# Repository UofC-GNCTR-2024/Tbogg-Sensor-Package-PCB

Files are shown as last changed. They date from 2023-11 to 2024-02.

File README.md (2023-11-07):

# Tbogg-Sensor-Package-PCB
The sensor package (strain, temperature, vibration) for the 2024 UofC GNCTR tbogg. Designed as an R&amp;D intrastructure monitoring solution.

## Main Components

1. **2x** Strain Gauge Blocks
	* Ulimately reads one of these two strain gauges:
		1. [100x BF350-3AA](https://www.aliexpress.com/item/595240806.html)
		2. [10x BX120-2AA](https://www.aliexpress.com/item/1005003672107724.html)
	* Based on [this schematic](https://www.elecrow.com/strain-gauge-module-p-735.html)
	* Sensing via HX711 chip
2. **1x** On-PCB Temperature Sensor (STDS75DS2F)
	* I2C
3. **2x** In-Concrete Temperature Sensors
	* Thermistor-based
4. **1x** Vibration Sensor
	* Model: MPU-6050 Breakout
	* I2C Comms
5. I2C Optical Flow Sensor
6. Battery: 4x 18650
	* TODO: choose quantity, model, holder, and connection
	* In series
7. Battery Management System: probably the 3V3 buck-boost from the balloon project
	* TODO: more info
8. Wireless Comms: LoRa Wio E5
	* TODO: pull from balloon project
	* TODO: confirm that this model is good
9. Microcontroller Unit (MCU)
	* ESP32 Breakout

## Reference Links
* TODO: fill

## Revision Notes
* PCB orders will each recieve a new revision number. 
	* PCB orders will be in the format of "Rev1", "Rev2", etc.
	* GitHub Releases (and Tags) will be tagged in the format of `rev1`, `rev2`, etc.
* BOM changes on PCB orders should be documented as minor revisions.
	* Example: `rev1.1`, `rev1.2`, etc.

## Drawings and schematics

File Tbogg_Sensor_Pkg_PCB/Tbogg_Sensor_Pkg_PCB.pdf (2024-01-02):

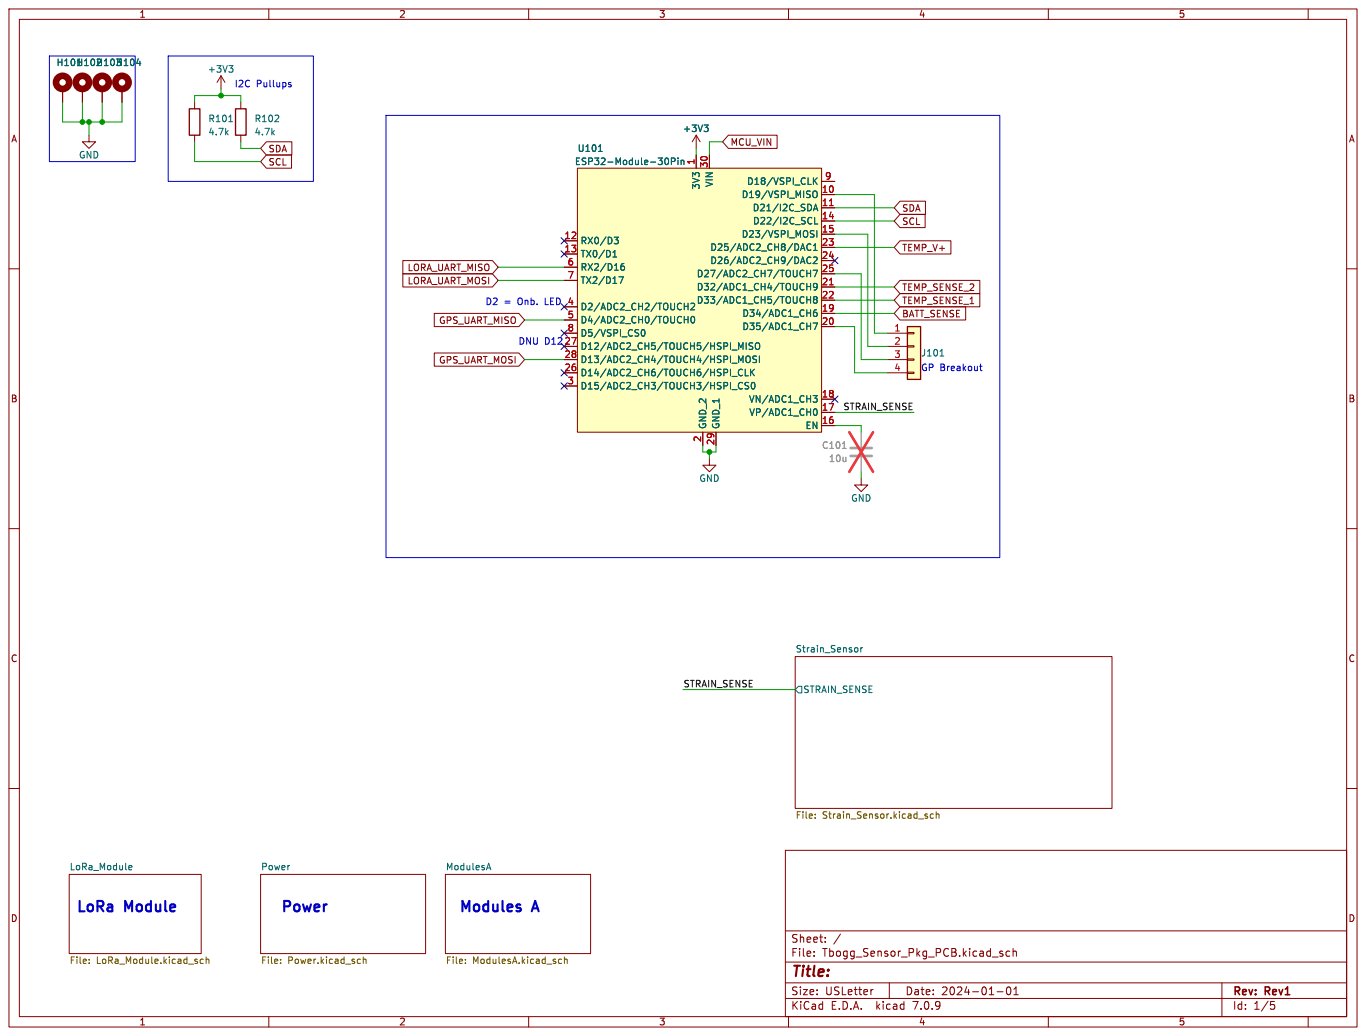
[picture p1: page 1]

File: ModulesA.kicad_sch Power File: Power.kicad_sch

Id: 1/5 Title: File: Tbogg_Sensor_Pkg_PCB.kicad_sch Sheet: / ModulesA

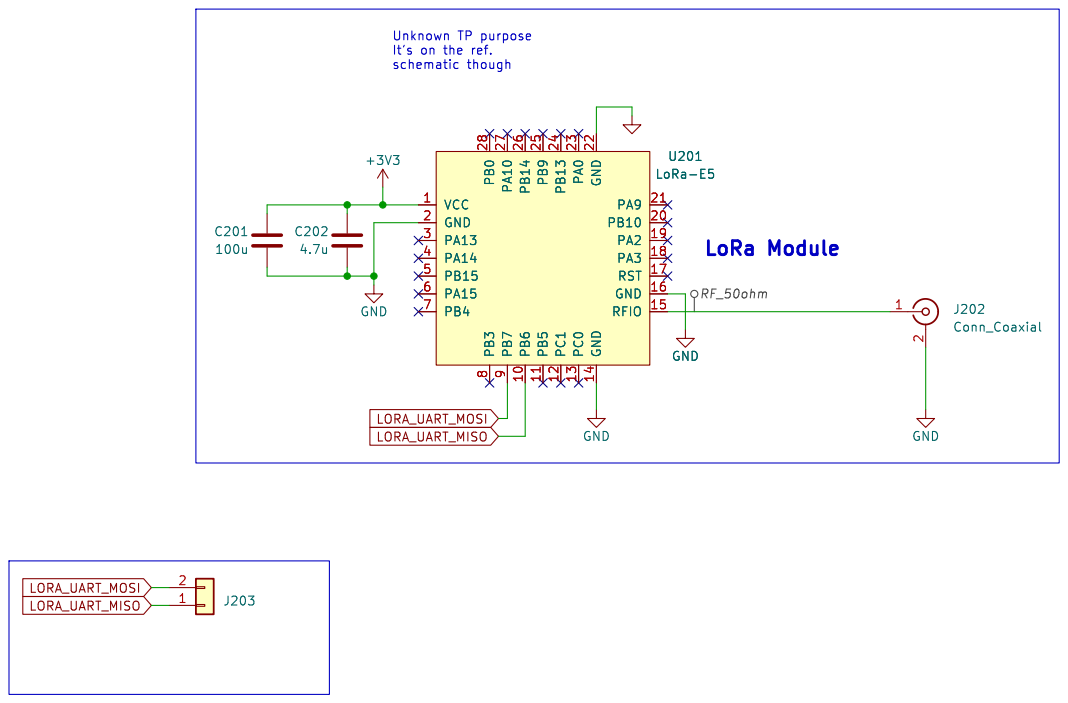
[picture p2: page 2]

Id: 2/5 Title: File: LoRa_Module.kicad_sch Sheet: /LoRa_Module/ GND

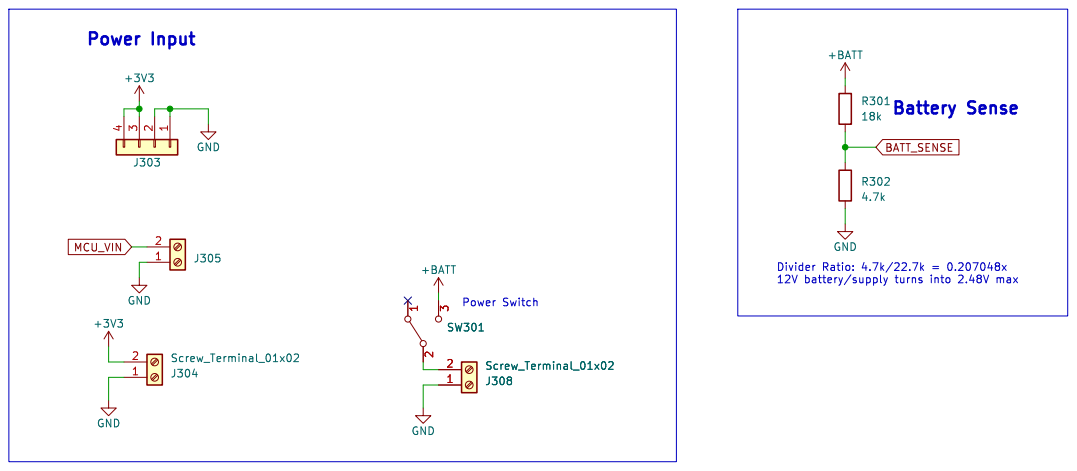
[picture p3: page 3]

J308 Screw_Terminal_01x02 +BATT GND GND GND

Id: 3/5 Title: File: Power.kicad_sch Sheet: /Power/

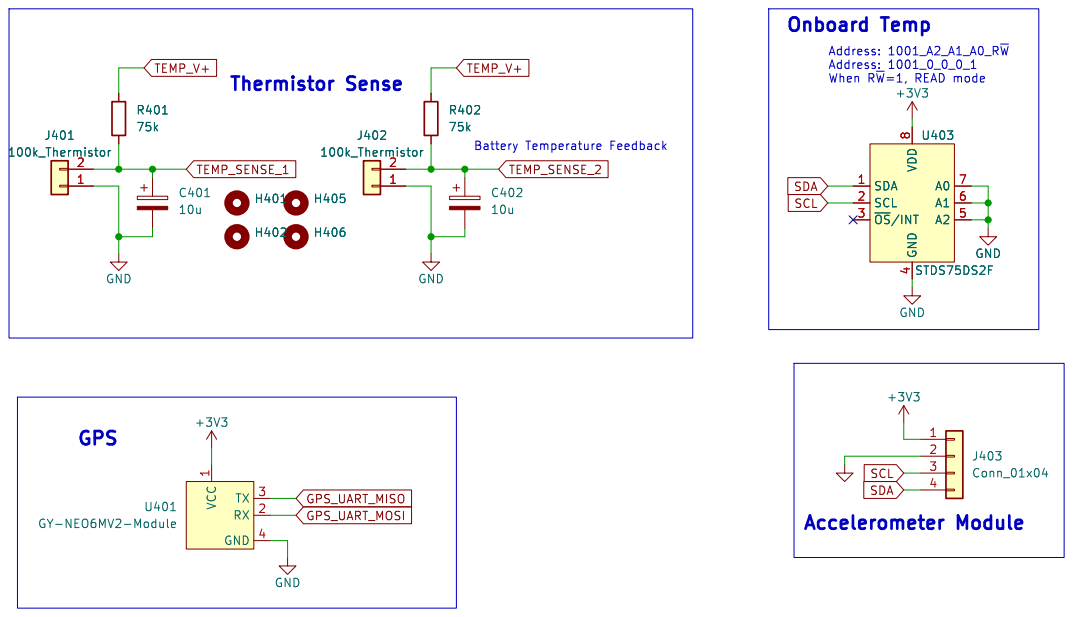
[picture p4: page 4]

1 RX 2 TX 3 GND 4 U401 GY-NEO6MV2-Module +3V3 GND
GPS

Id: 4/5 Title: File: ModulesA.kicad_sch Sheet: /ModulesA/

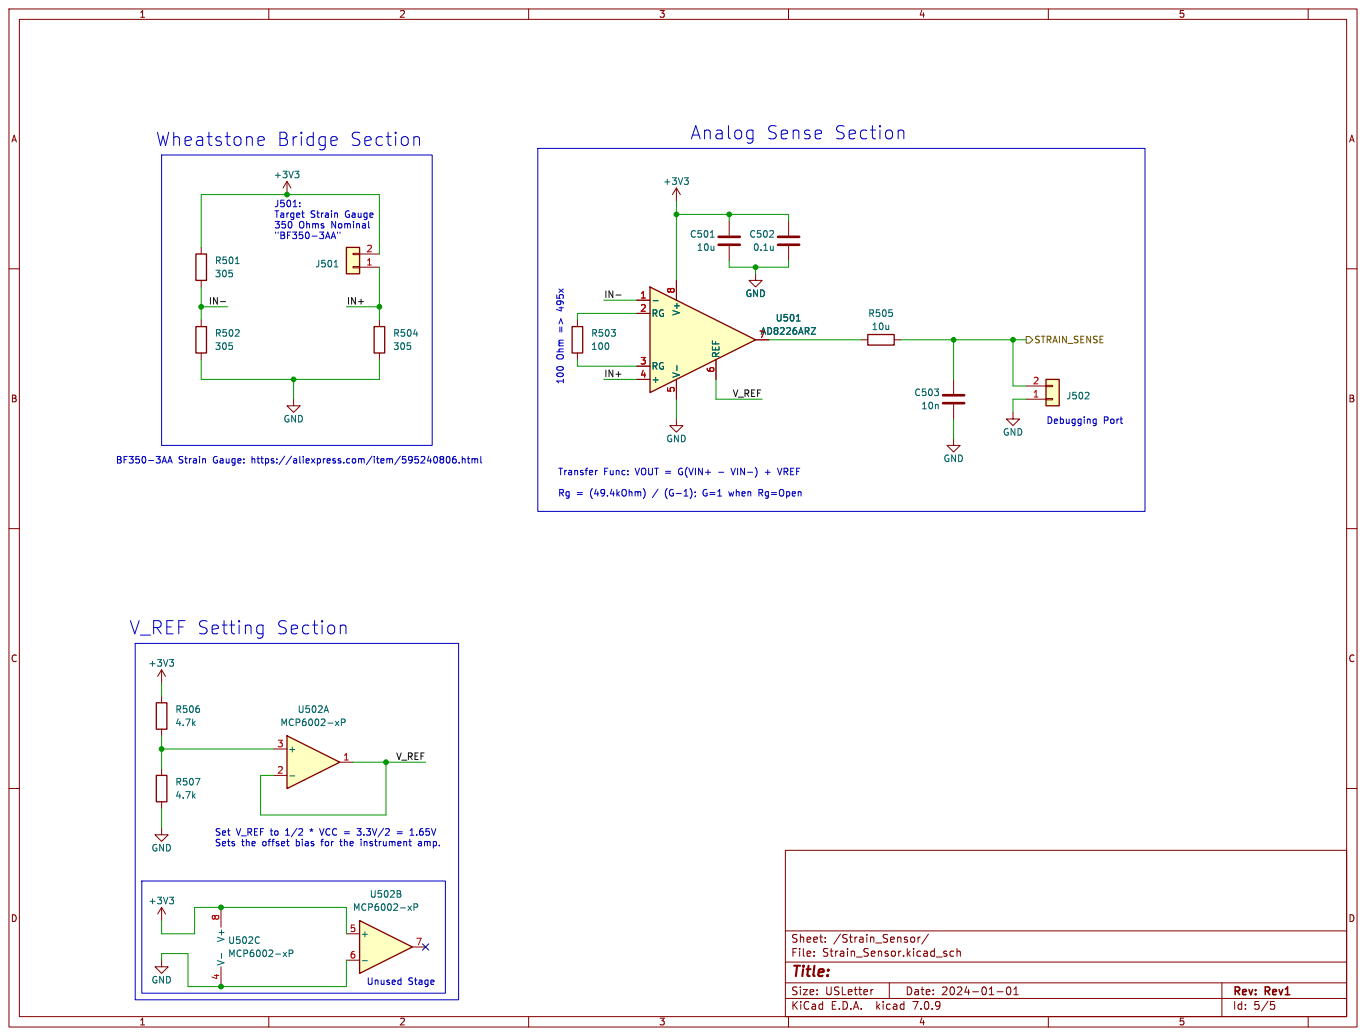
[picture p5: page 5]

350 Ohms Nominal "BF350-3AA" Wheatstone Bridge Section

Id: 5/5 Title: File: Strain_Sensor.kicad_sch Sheet: /Strain_Sensor/

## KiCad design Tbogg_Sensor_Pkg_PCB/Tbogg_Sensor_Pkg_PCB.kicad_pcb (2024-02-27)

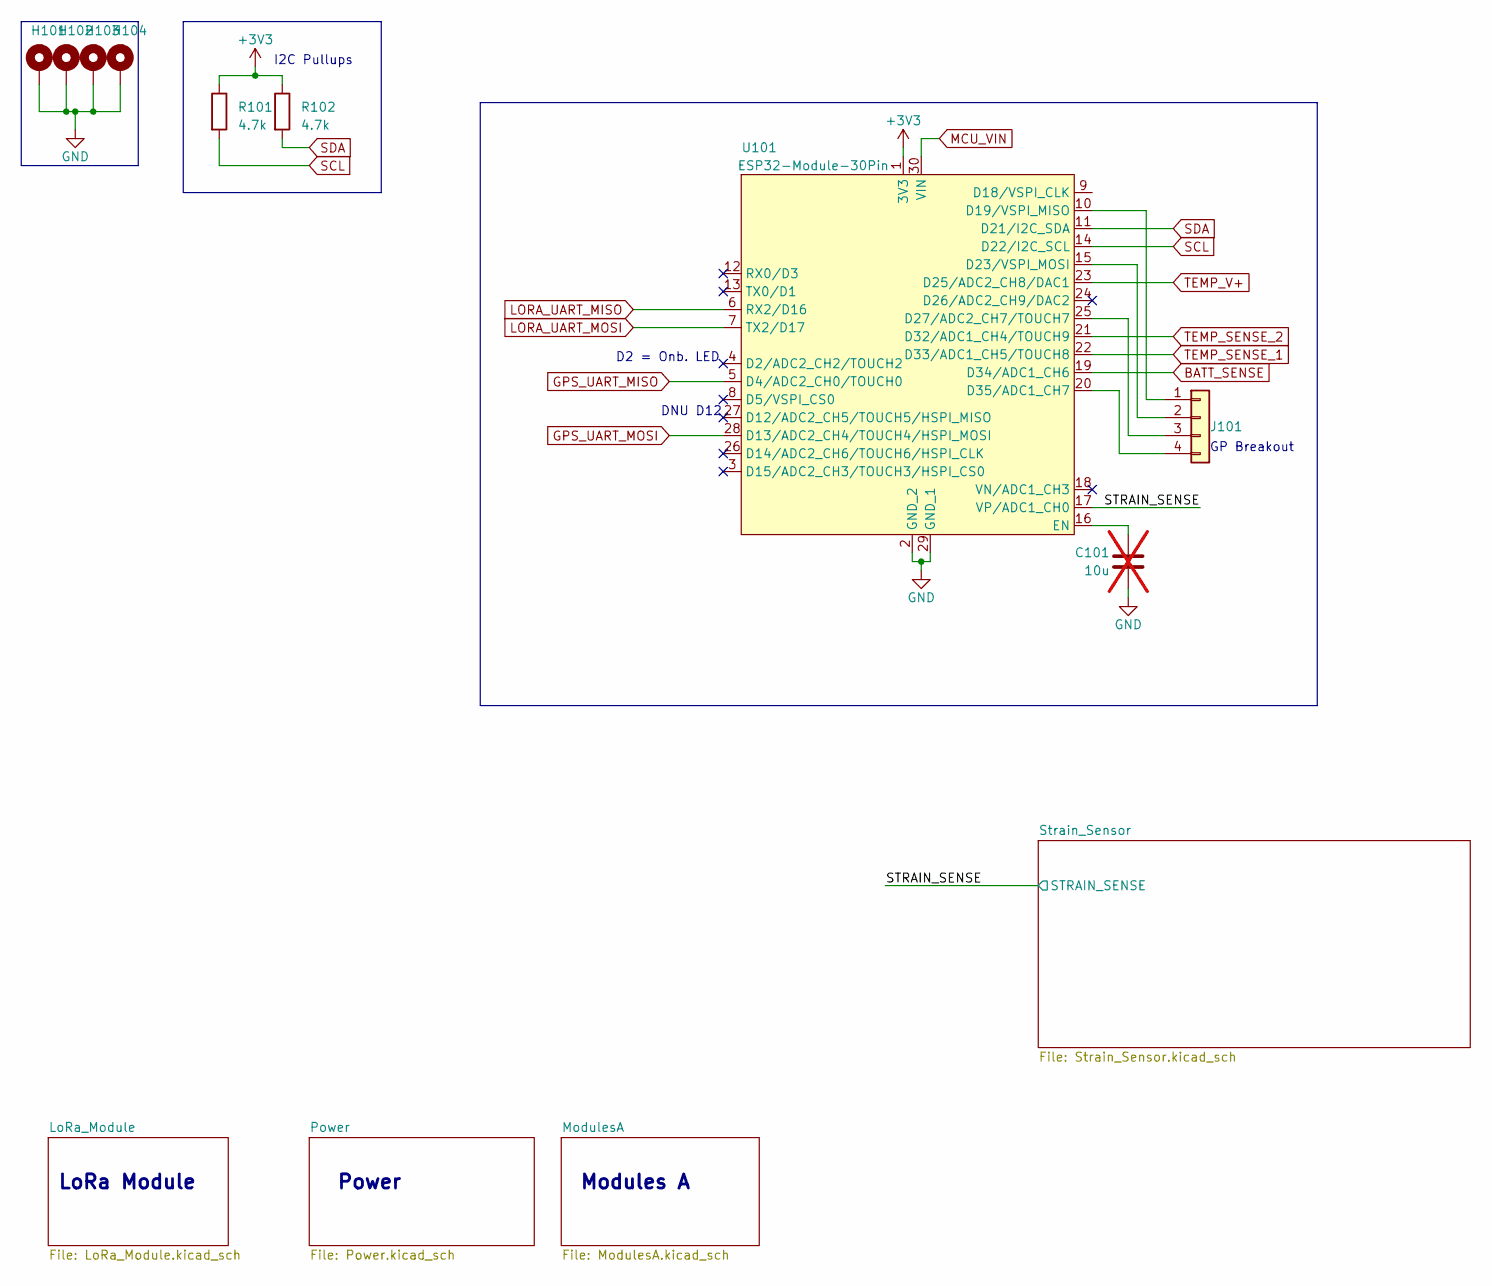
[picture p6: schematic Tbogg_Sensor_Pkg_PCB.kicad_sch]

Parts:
C101: 10u; C_1206_3216Metric_Pad1.33x1.80mm_HandSolder; not fitted
H101, H102, H103, H104: MountingHole_Pad; MountingHole_3.2mm_M3_DIN965_Pad
J101: Conn_01x04; PinHeader_1x04_P2.54mm_Vertical
R101, R102: 4.7k; R_1206_3216Metric_Pad1.30x1.75mm_HandSolder
U101: ESP32-Module-30Pin

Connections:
BATT_SENSE: U101.19 (D34/ADC1_CH6); also elsewhere on the board
GND: C101.2, H101.1, H102.1, H103.1, H104.1, U101.2 (GND_2), U101.29 (GND_1); also elsewhere on the board
GPS_UART_MISO: U101.5 (D4/ADC2_CH0/TOUCH0); also elsewhere on the board
GPS_UART_MOSI: U101.28 (D13/ADC2_CH4/TOUCH4/HSPI_MOSI); also elsewhere on the board
LORA_UART_MISO: U101.6 (RX2/D16); also elsewhere on the board
LORA_UART_MOSI: U101.7 (TX2/D17); also elsewhere on the board
MCU_VIN: U101.30 (VIN); also elsewhere on the board
unnamed: J101.1, U101.10 (D19/VSPI_MISO)
unnamed: J101.2, U101.15 (D23/VSPI_MOSI)
unnamed: J101.3, U101.25 (D27/ADC2_CH7/TOUCH7)
unnamed: J101.4, U101.20 (D35/ADC1_CH7)
unnamed: C101.1, U101.16 (EN)
SCL: R101.2, U101.14 (D22/I2C_SCL); also elsewhere on the board
SDA: R102.2, U101.11 (D21/I2C_SDA); also elsewhere on the board
TEMP_SENSE_1: U101.22 (D33/ADC1_CH5/TOUCH8); also elsewhere on the board
TEMP_SENSE_2: U101.21 (D32/ADC1_CH4/TOUCH9); also elsewhere on the board
TEMP_V+: U101.23 (D25/ADC2_CH8/DAC1); also elsewhere on the board

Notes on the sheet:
LoRa Module
GP Breakout
D2 = Onb. LED
Modules A
DNU D12
Power
I2C Pullups

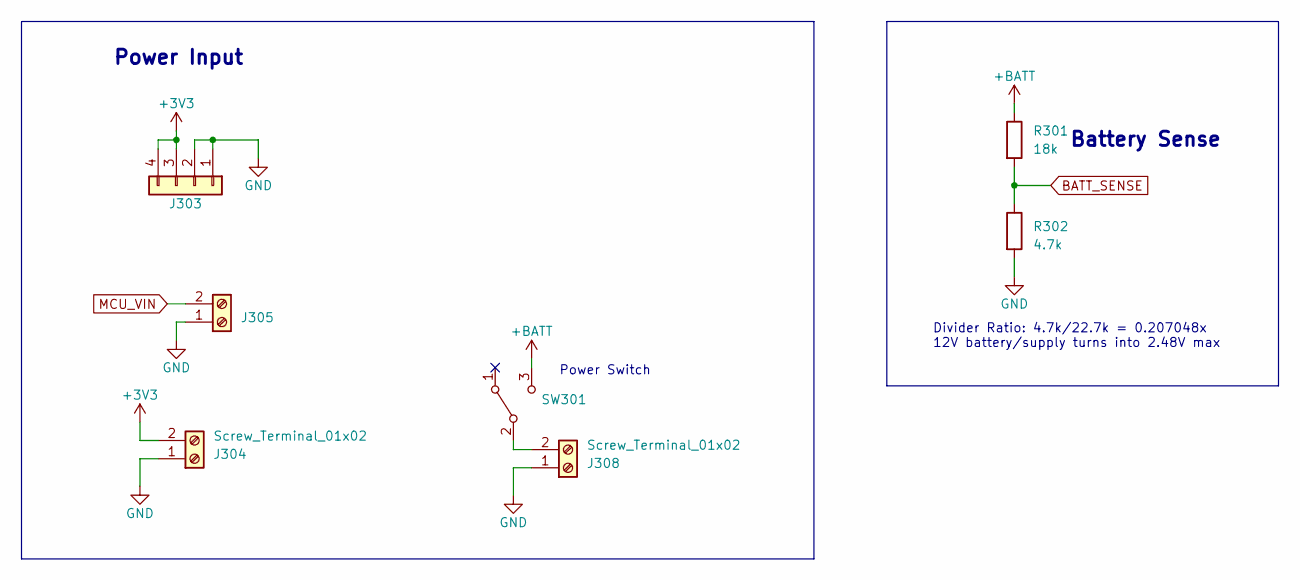
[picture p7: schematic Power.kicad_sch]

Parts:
J303: Conn_01x04; PinHeader_1x04_P2.54mm_Vertical
J304, J305, J308: Screw_Terminal_01x02; TerminalBlock_bornier-2_P5.08mm
R301: 18k; R_1206_3216Metric_Pad1.30x1.75mm_HandSolder
R302: 4.7k; R_1206_3216Metric_Pad1.30x1.75mm_HandSolder
SW301: SW_SPDT; SW_Slide_1P2T_CK_OS102011MS2Q

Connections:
+BATT: R301.1, SW301.3 (C)
BATT_SENSE: R301.2, R302.1; also elsewhere on the board
GND: J303.1, J303.2, J304.1, J305.1, J308.1, R302.2; also elsewhere on the board
MCU_VIN: J305.2; also elsewhere on the board
unnamed: J308.2, SW301.2 (B)

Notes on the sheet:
Divider Ratio: 4.7k/22.7k = 0.207048x 12V battery/supply turns into 2.48V max
Power Switch
Battery Sense
Power Input

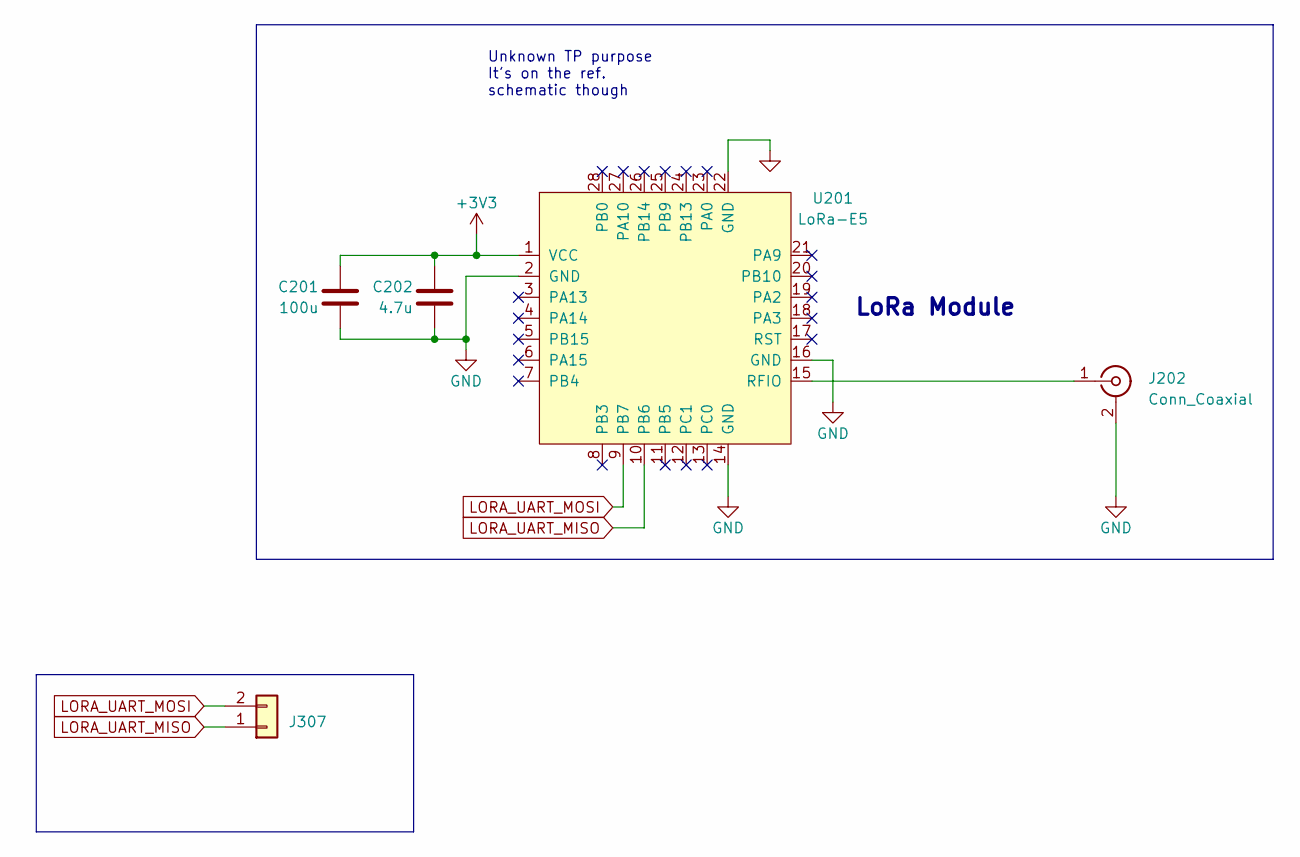
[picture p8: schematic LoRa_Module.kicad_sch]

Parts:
C201: 100u; C_1206_3216Metric_Pad1.33x1.80mm_HandSolder
C202: 4.7u; C_1206_3216Metric_Pad1.33x1.80mm_HandSolder
J202: Conn_Coaxial; SMA_Wurth_60312002114503_Vertical
J307: Conn_01x02; PinHeader_1x02_P2.54mm_Vertical
U201: LoRa-E5; LoRa-E5_HandSolder

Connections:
GND: C201.2, C202.2, J202.2 (Ext), U201.2 (GND), U201.14 (GND), U201.16 (GND), U201.22 (GND); also elsewhere on the board
LORA_UART_MISO: U201.10 (PB6); also elsewhere on the board
LORA_UART_MOSI: U201.9 (PB7); also elsewhere on the board
unnamed: J202.1 (In), U201.15 (RFIO)

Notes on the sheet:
Unknown TP purpose It's on the ref. schematic though
LoRa Module

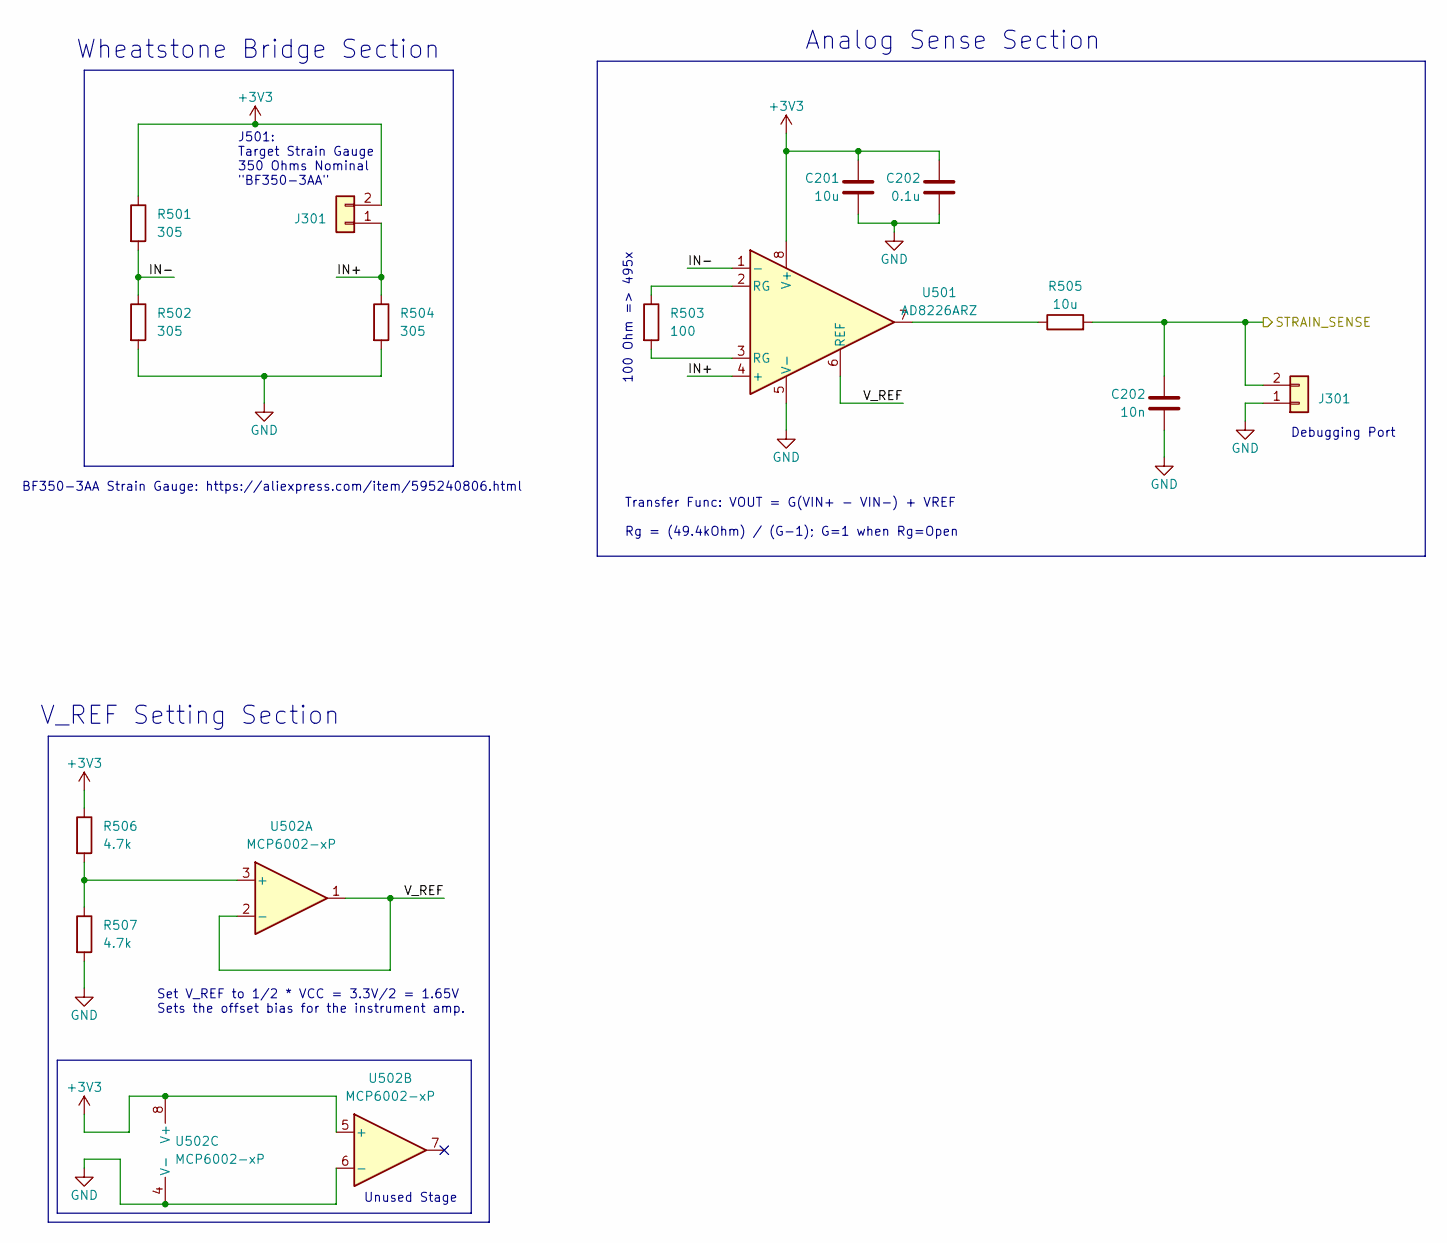
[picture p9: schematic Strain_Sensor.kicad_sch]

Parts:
C201: 10u; C_1206_3216Metric_Pad1.33x1.80mm_HandSolder
C202: 0.1u; C_1206_3216Metric_Pad1.33x1.80mm_HandSolder
J301: Conn_01x02; PinHeader_1x02_P2.54mm_Vertical
R501, R502, R504: 305; InactiveStrainGauge
R503: 100; R_1206_3216Metric_Pad1.30x1.75mm_HandSolder
R505: 10u; R_1206_3216Metric_Pad1.30x1.75mm_HandSolder
R506, R507: 4.7k; R_1206_3216Metric_Pad1.30x1.75mm_HandSolder
U501: AD8226ARZ; SO-8_3.9x4.9mm_P1.27mm
U502: MCP6002-xP; DIP-8_W7.62mm_LongPads

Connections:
/Strain_Sensor/IN+: R504.1, U501.4 (+); also elsewhere on the board
/Strain_Sensor/IN-: R501.2, R502.1, U501.1 (-)
/Strain_Sensor/V_REF: U501.6 (REF), U502.1, U502.2 (-)
GND: C201.2, C202.2, R502.2, R504.2, R507.2, U501.5 (V-), U502.4 (V-), U502.6 (-); also elsewhere on the board
unnamed: R503.1, U501.2 (RG)
unnamed: R503.2, U501.3 (RG)
unnamed: R505.1, U501.7
unnamed: R506.2, R507.1, U502.3 (+)

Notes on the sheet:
Unused Stage
J501: Target Strain Gauge 350 Ohms Nominal "BF350-3AA"
Debugging Port
V_REF Setting Section
Transfer Func: VOUT = G(VIN+ − VIN−) + VREF Rg = (49.4kOhm) / (G-1); G=1 when Rg=Open
100 Ohm => 495x
BF350-3AA Strain Gauge: https://aliexpress.com/item/595240806.html
Set V_REF to 1/2 * VCC = 3.3V/2 = 1.65V Sets the offset bias for the instrument amp.
Wheatstone Bridge Section
Analog Sense Section

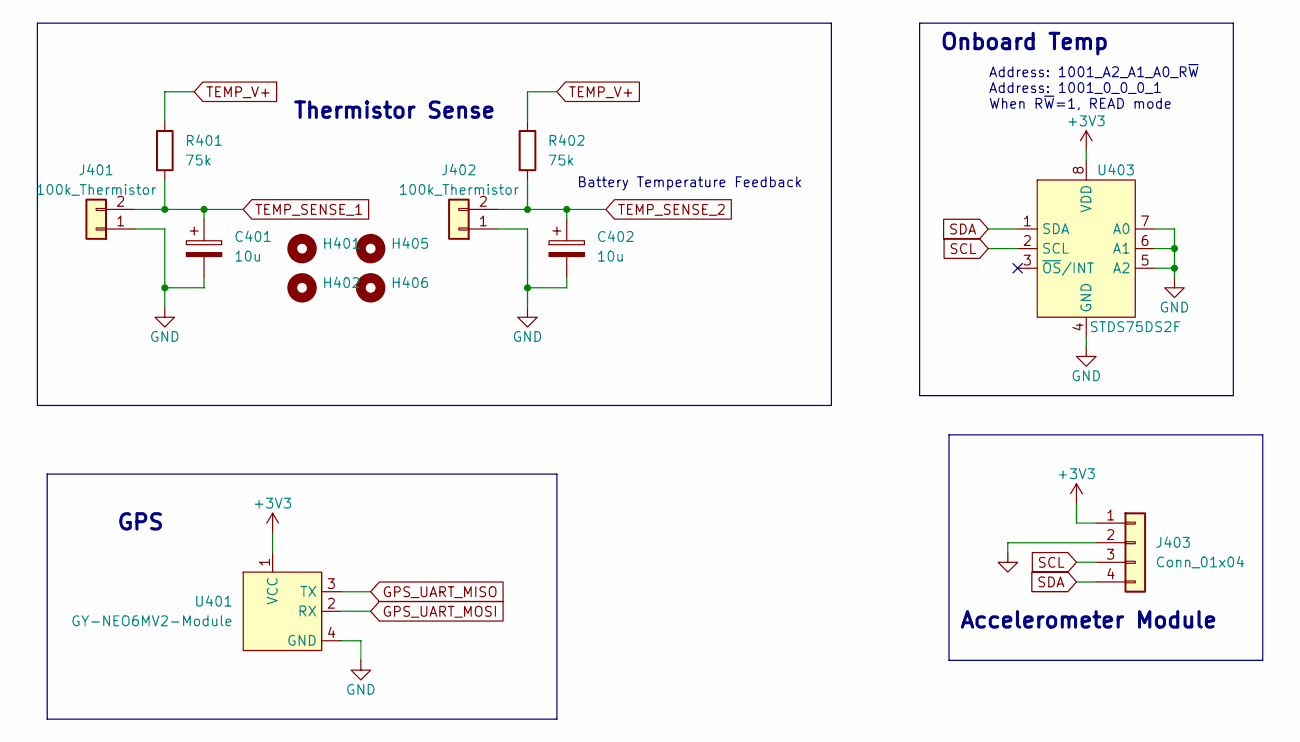
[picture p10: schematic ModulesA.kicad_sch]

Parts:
C401, C402: 10u; C_1206_3216Metric_Pad1.33x1.80mm_HandSolder
H401, H402, H405, H406: MountingHole; MountingHole_2mm
J401, J402: 100k_Thermistor; PinHeader_1x02_P2.54mm_Vertical
J403: Conn_01x04; PinHeader_1x04_P2.54mm_Vertical
R401, R402: 75k; R_1206_3216Metric_Pad1.30x1.75mm_HandSolder
U401: GY-NEO6MV2-Module
U403: STDS75DS2F; MSOP-8_3x3mm_P0.65mm; LCSC C283289

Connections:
GND: C401.2, C402.2, J401.1, J402.1, J403.2, U401.4 (GND), U403.4 (GND), U403.5 (A2), U403.6 (A1), U403.7 (A0); also elsewhere on the board
GPS_UART_MISO: U401.3 (TX); also elsewhere on the board
GPS_UART_MOSI: U401.2 (RX); also elsewhere on the board
SCL: J403.3, U403.2 (SCL); also elsewhere on the board
SDA: J403.4, U403.1 (SDA); also elsewhere on the board
TEMP_SENSE_1: C401.1, J401.2, R401.2; also elsewhere on the board
TEMP_SENSE_2: C402.1, J402.2, R402.2; also elsewhere on the board
TEMP_V+: R401.1, R402.1; also elsewhere on the board

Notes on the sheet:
Accelerometer Module
Onboard Temp
Address: 1001_A2_A1_A0_R~{W} Address: 1001_0_0_0_1 When R~{W}=1, READ mode
GPS
Thermistor Sense
Battery Temperature Feedback

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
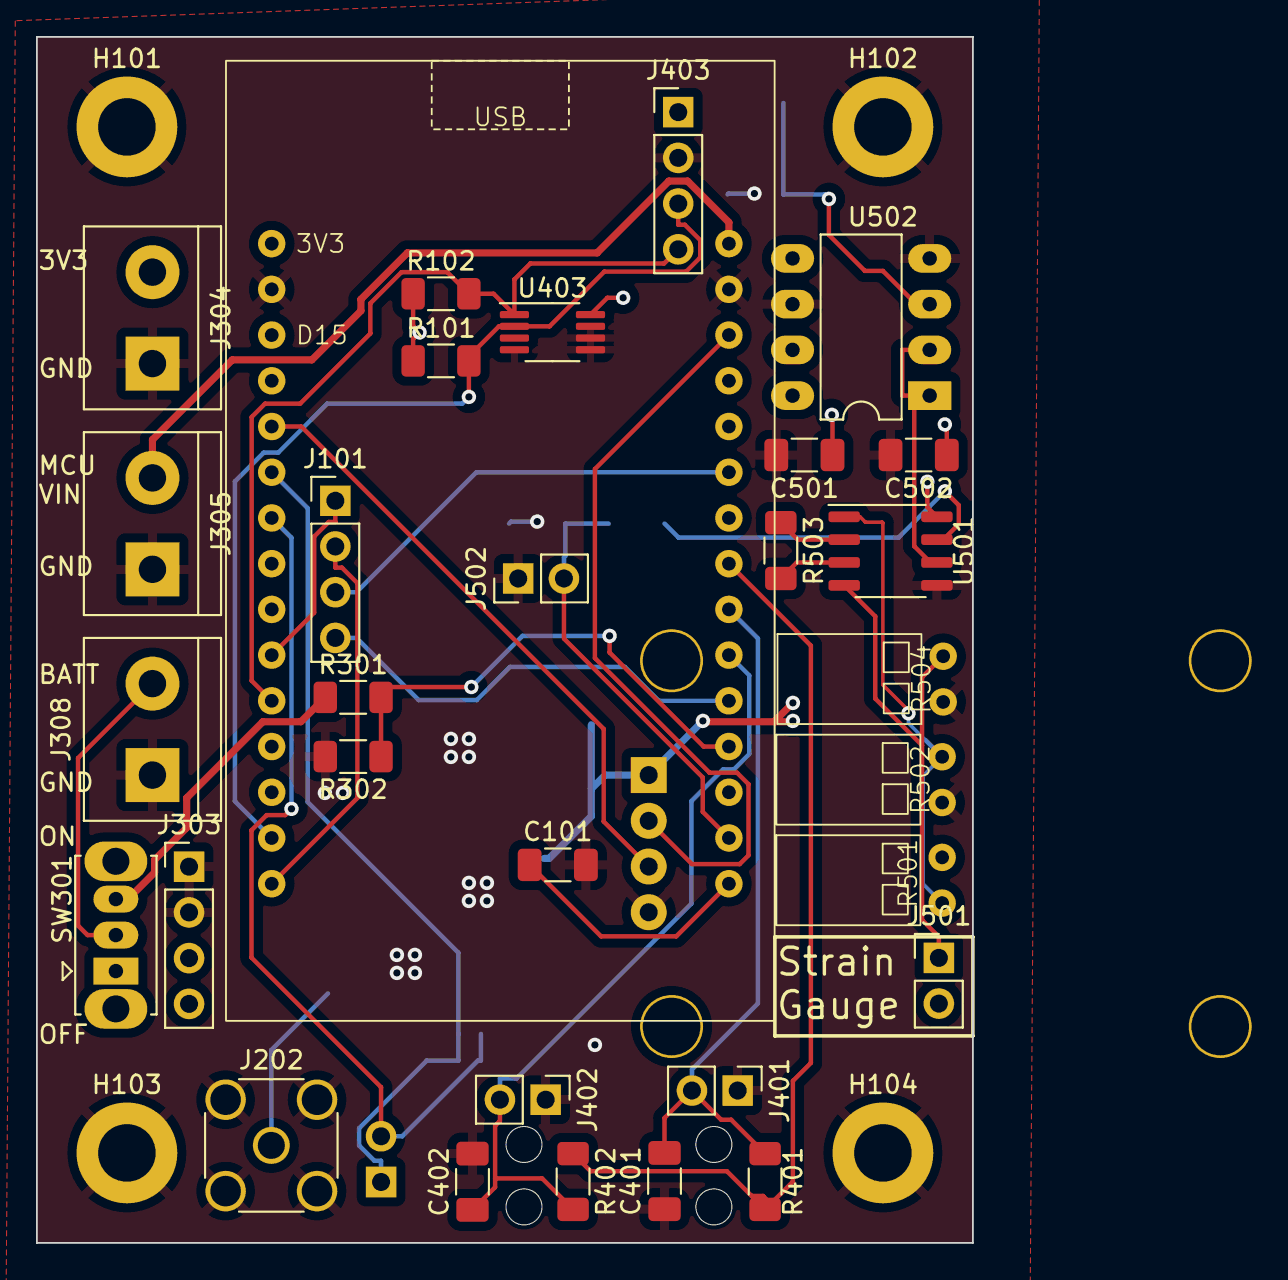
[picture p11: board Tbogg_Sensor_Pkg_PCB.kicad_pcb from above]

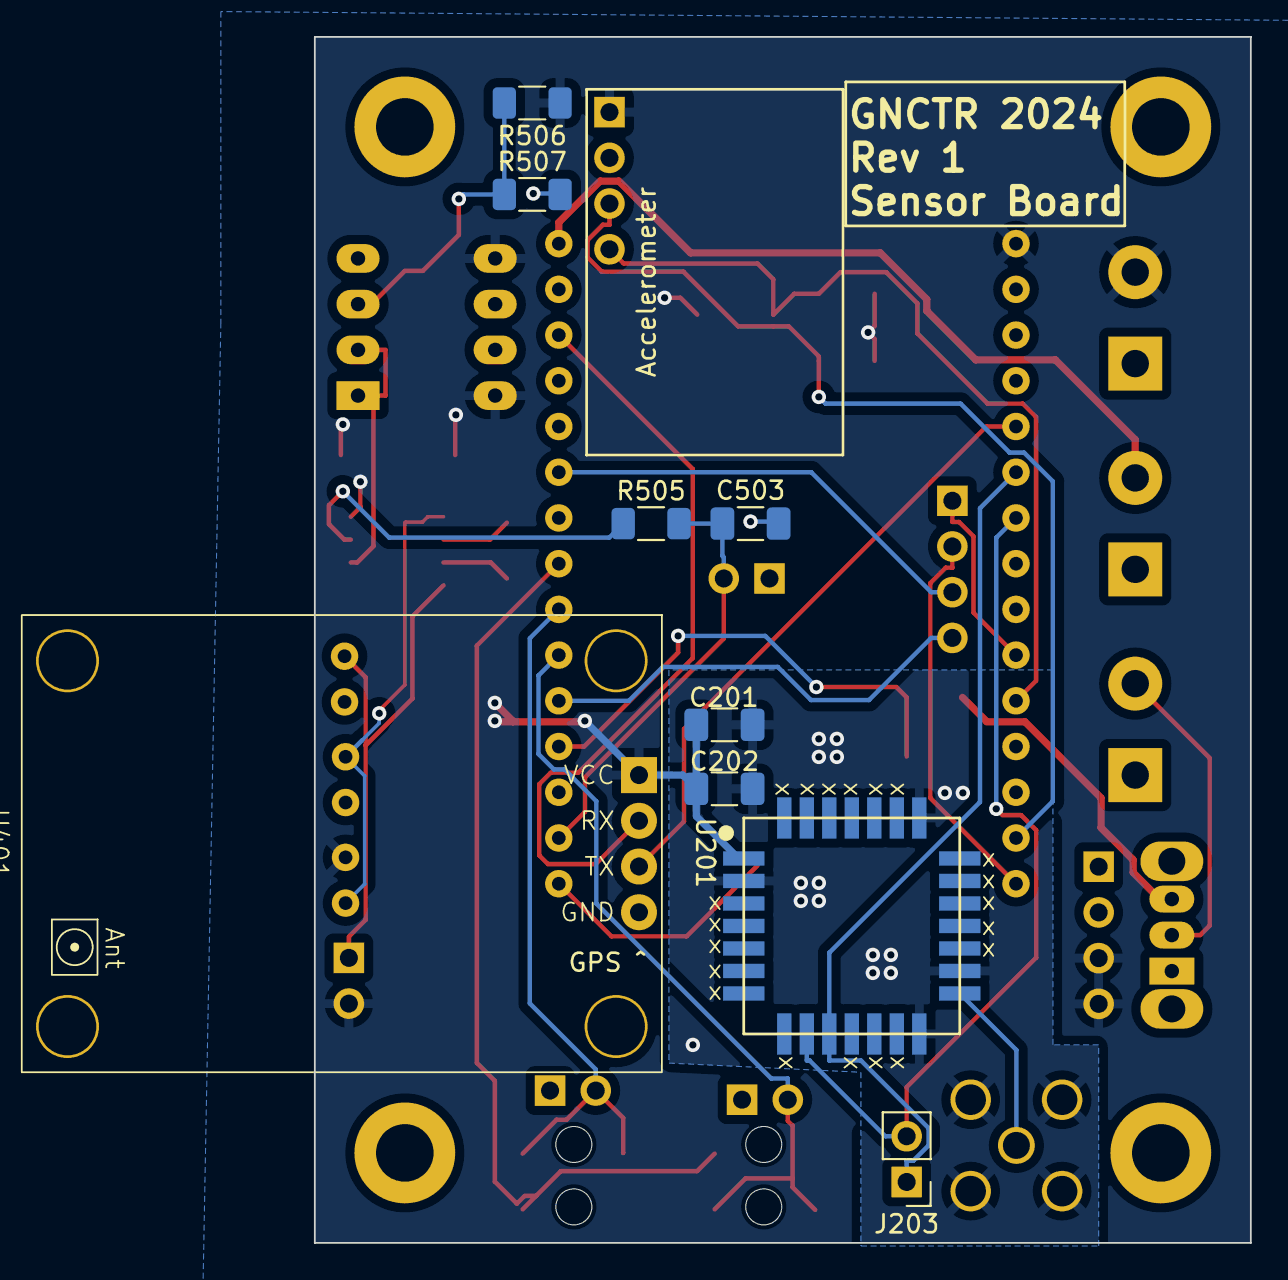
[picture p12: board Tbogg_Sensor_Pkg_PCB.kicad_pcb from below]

Board: 2 copper layers, 52.0 x 67.0 mm, 48 parts (9 on the bottom side), 29 nets.

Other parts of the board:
C501: 10u; C_1206_3216Metric_Pad1.33x1.80mm_HandSolder
C502: 0.1u; C_1206_3216Metric_Pad1.33x1.80mm_HandSolder
C503: 10n; C_1206_3216Metric_Pad1.33x1.80mm_HandSolder
J203, J501, J502: Conn_01x02; PinHeader_1x02_P2.54mm_Vertical

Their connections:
/Strain_Sensor/IN+: J501.1; also elsewhere on the board
GND: C501.2, C502.2, C503.2, J502.1; also elsewhere on the board
LORA_UART_MISO: J203.1; also elsewhere on the board
LORA_UART_MOSI: J203.2; also elsewhere on the board

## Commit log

2023-11-06 Add starting point repo
    [Tbogg_Sensor_Pkg_PCB.kicad_pcb, Tbogg_Sensor_Pkg_PCB.kicad_sch]
2023-12-31 Add base from other project
    [LoRa_Module.kicad_sch, ModulesA.kicad_sch, Power.kicad_sch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]
2024-01-01 Finish design
    [LoRa_Module.kicad_sch, ModulesA.kicad_sch, Power.kicad_sch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]
2024-01-01 Tiny reroutes, labels
    [Tbogg_Sensor_Pkg_PCB.kicad_pcb]
2024-01-01 Export Rev1 Gerber
    [Tbogg_Sensor_Pkg_PCB.kicad_pcb]
2024-01-02 Plot rev1 schematic with rev number
    [LoRa_Module.kicad_sch, ModulesA.kicad_sch, Power.kicad_sch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]
2024-02-27 Fix enclosure dimension on PCB comments layer
    [Tbogg_Sensor_Pkg_PCB.kicad_pcb]
